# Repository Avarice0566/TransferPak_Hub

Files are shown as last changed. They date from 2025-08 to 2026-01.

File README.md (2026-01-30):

# TransferPakHub

This repository provides a standalone Transfer Pak hub PCB designed to fit inside an N64 DexDrive case.  

## Requirements
- Transplant all surface-mount and DIP components from an **N64 controller PCB** (model: `CFS8120-200010-00`).  
- Optionally, add a **1.8mm LED** with the appropriate resistor to utilize the DexDrive case’s LED diffuser.
- Digikey Part No. SW1139-ND can be used to plug the DC jack hole in the dexdrive case

## Notes
- All DIP components are mounted on the opposite side of the board for clearance.  
- **Use at your own risk.** I am not responsible for any damage to your N64, its accessories, or your Game Boy cartridges.  

N64TP_HUB

- Bottom label. Replaces Interact DEXDRIVE label with something that looks more akin to a real Nintendo product. (The label needs to be 26mm in height and 35mm in width)

TPpak hub label

Special thanks to Modman(RWeick), Bigbass, and everyone on the N64BREW Discord.

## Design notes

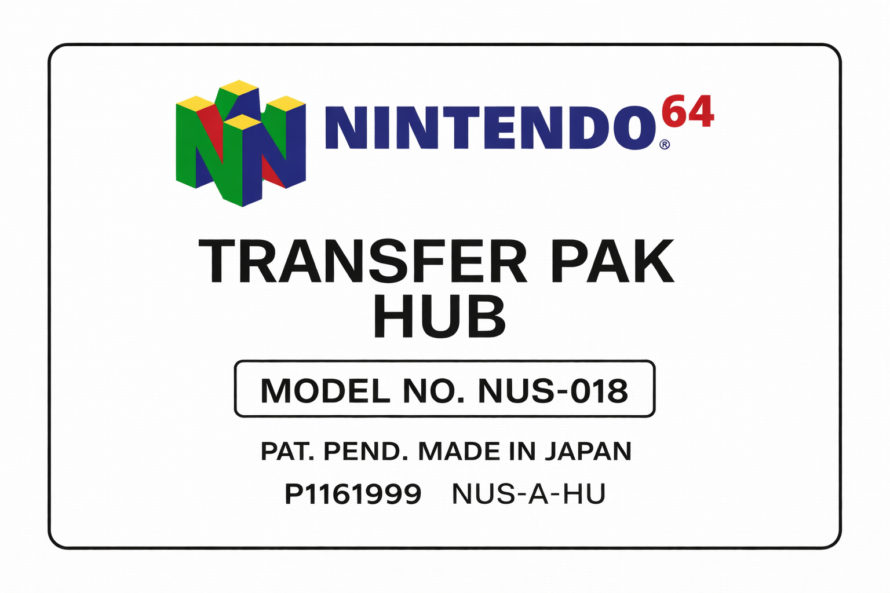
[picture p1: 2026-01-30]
TPpak hub label.png

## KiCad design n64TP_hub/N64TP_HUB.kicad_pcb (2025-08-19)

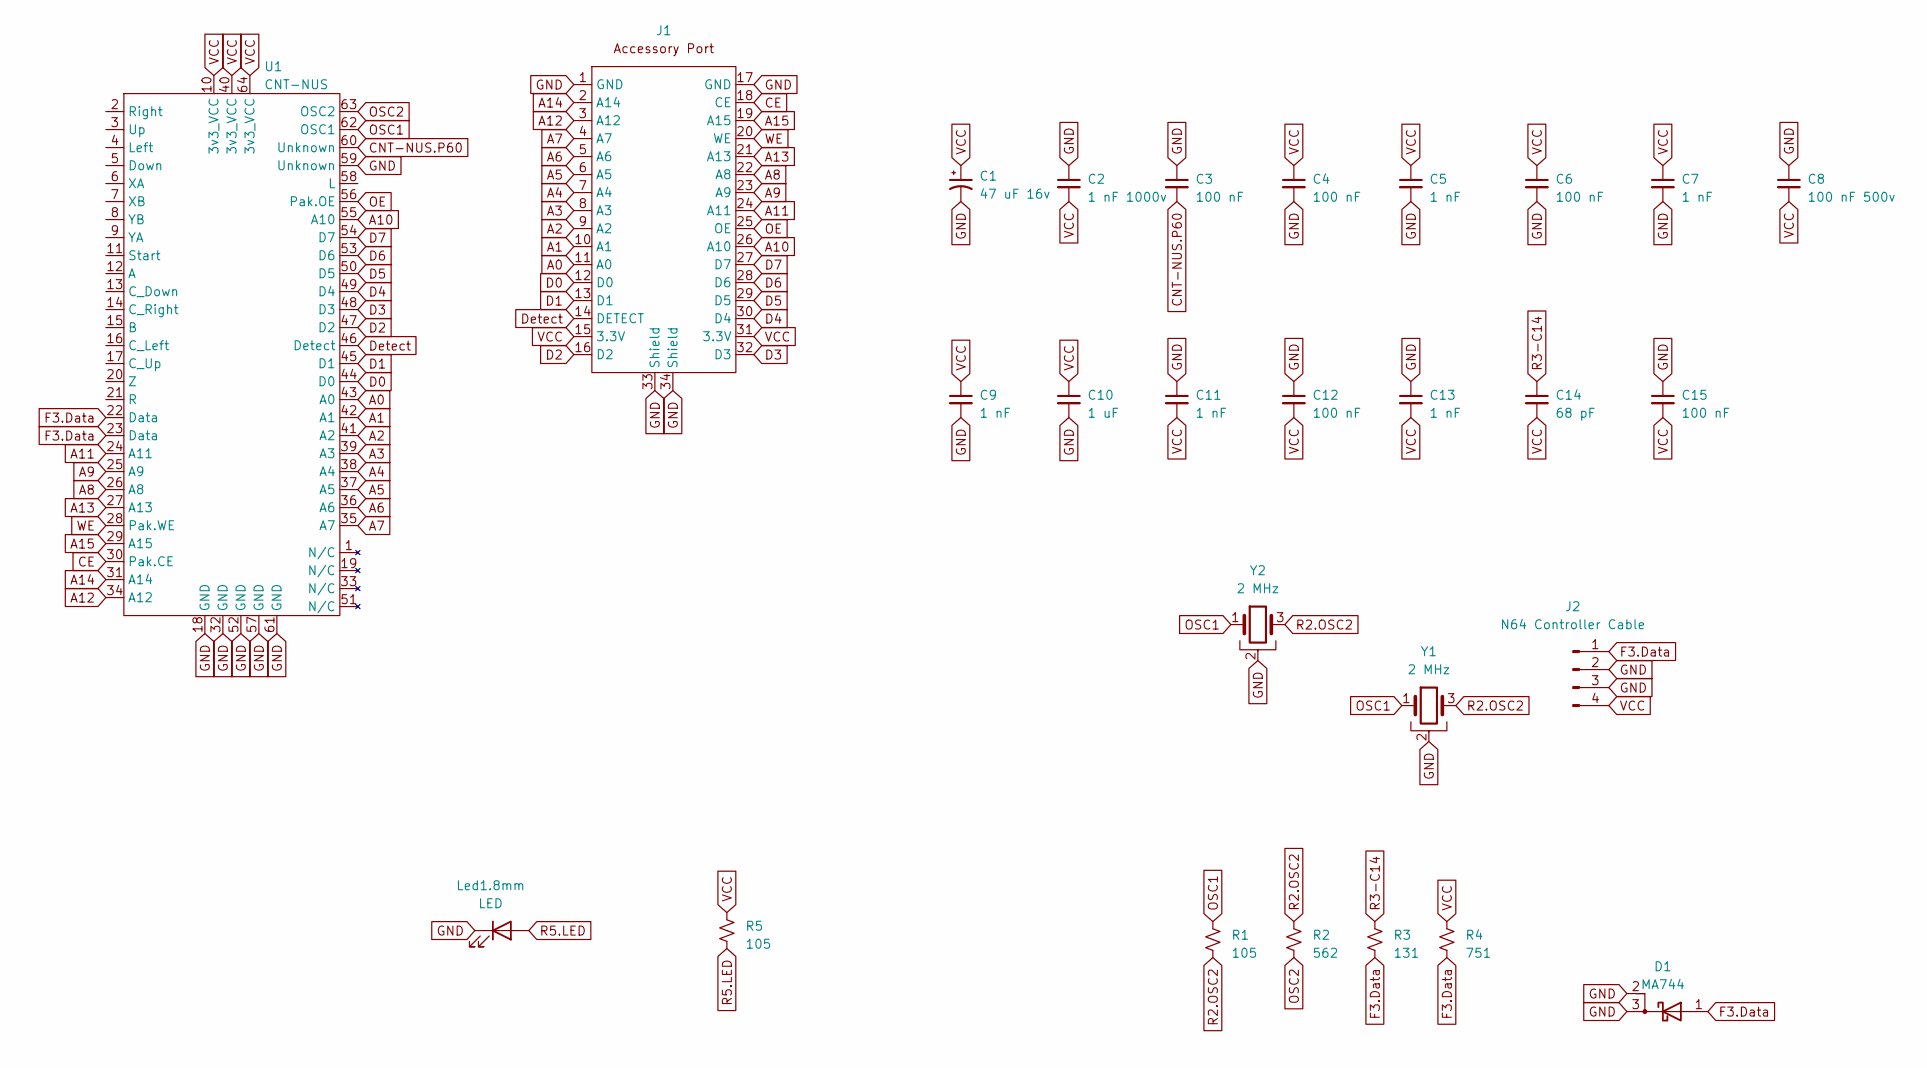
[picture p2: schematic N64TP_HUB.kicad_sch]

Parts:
C1: 47 uF 16v; CP_Radial_D5.0mm_P2.50mm
C2: 1 nF 1000v; TH Capacitor
C3, C4, C6, C12, C15: 100 nF; Small SMD
C5, C7, C9, C11, C13: 1 nF; Small SMD
C8: 100 nF 500v; TH Capacitor
C10: 1 uF; Small SMD
C14: 68 pF; Small SMD
D1: MA744; SOT-23 Diode
J1: Accessory Port
J2: N64 Controller Cable; N64 Plug Cable Connector
Led1.8mm: LED
R1, R5: 105; Large SMD
R2: 562; Large SMD
R3: 131; Small SMD
R4: 751; Small SMD
U1: CNT-NUS
Y1: 2 MHz; 2 MHz Oscillator
Y2: 2 MHz; 2 Mhz Oscillator SMD

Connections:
A: U1.12 (A)
A0: J1.11 (A0), U1.43 (A0)
A1: J1.10 (A1), U1.42 (A1)
A2: J1.9 (A2), U1.41 (A2)
A3: J1.8 (A3), U1.39 (A3)
A4: J1.7 (A4), U1.38 (A4)
A5: J1.6 (A5), U1.37 (A5)
A6: J1.5 (A6), U1.36 (A6)
A7: J1.4 (A7), U1.35 (A7)
A8: J1.22 (A8), U1.26 (A8)
A9: J1.23 (A9), U1.25 (A9)
A10: J1.26 (A10), U1.55 (A10)
A11: J1.24 (A11), U1.24 (A11)
A12: J1.3 (A12), U1.34 (A12)
A13: J1.21 (A13), U1.27 (A13)
A14: J1.2 (A14), U1.31 (A14)
A15: J1.19 (A15), U1.29 (A15)
B: U1.15 (B)
CD: U1.13 (C_Down)
CE: J1.18 (CE), U1.30 (Pak.CE)
CL: U1.16 (C_Left)
CNT-NUS.P60: C3.2, U1.60 (Unknown)
CR: U1.14 (C_Right)
CU: U1.17 (C_Up)
D0: J1.12 (D0), U1.44 (D0)
D1: J1.13 (D1), U1.45 (D1)
D2: J1.16 (D2), U1.47 (D2)
D3: J1.32 (D3), U1.48 (D3)
D4: J1.30 (D4), U1.49 (D4)
D5: J1.29 (D5), U1.50 (D5), U1.51 (D5)
D6: J1.28 (D6), U1.53 (D6)
D7: J1.27 (D7), U1.54 (D7)
Detect: J1.14 (DETECT), U1.46 (Detect)
Down: U1.5 (Down)
F3.Data: D1.1 (A), J2.1, R3.2, R4.2, U1.22 (Data), U1.23 (Data)
GND: C1.2, C2.1, C3.1, C4.2, C5.2, C6.2, C7.2, C8.1, C9.2, C10.2, C11.1, C12.1, C13.1, C15.1, D1.2 (K), D1.3 (K), J1.1 (GND), J1.17 (GND), J1.33 (Shield), J1.34 (Shield), J2.2, J2.3, Led1.8mm.1 (K), U1.18 (GND), U1.19 (Unknown), U1.32 (GND), U1.52 (GND), U1.57 (GND), U1.59 (Unknown), U1.61 (GND), Y1.2, Y2.2; also elsewhere on the board
L: U1.58 (L)
Left: U1.4 (Left)
OE: J1.25 (OE), U1.56 (Pak.OE)
OSC1: R1.1, U1.62 (OSC1), Y1.1, Y2.1
OSC2: R2.2, U1.63 (OSC2)
R: U1.21 (R)
R2.OSC2: R1.2, R2.1, Y1.3, Y2.3
R3-C14: C14.1, R3.1
Right: U1.2 (Right)
Start: U1.11 (Start)
Up: U1.3 (Up)
WE: J1.20 (WE), U1.28 (Pak.WE)
XA: U1.6 (XA)
XB: U1.7 (XB)
YA: U1.9 (YA)
YB: U1.8 (YB)
Z: U1.20 (Z)

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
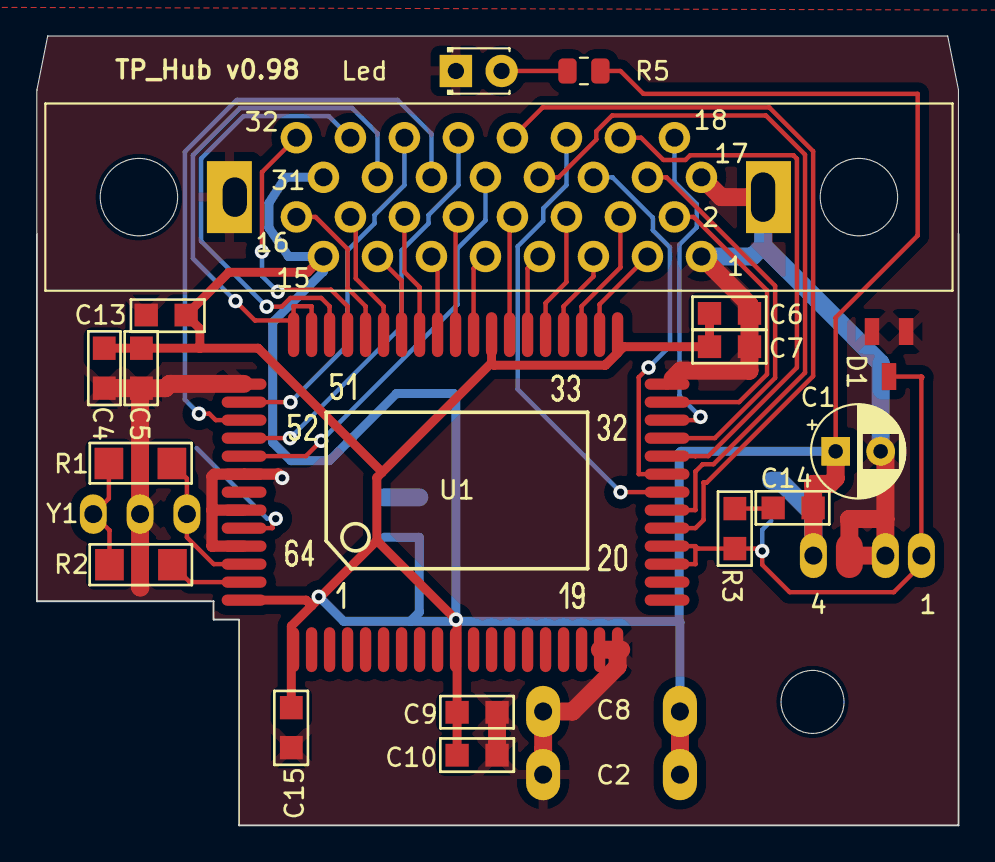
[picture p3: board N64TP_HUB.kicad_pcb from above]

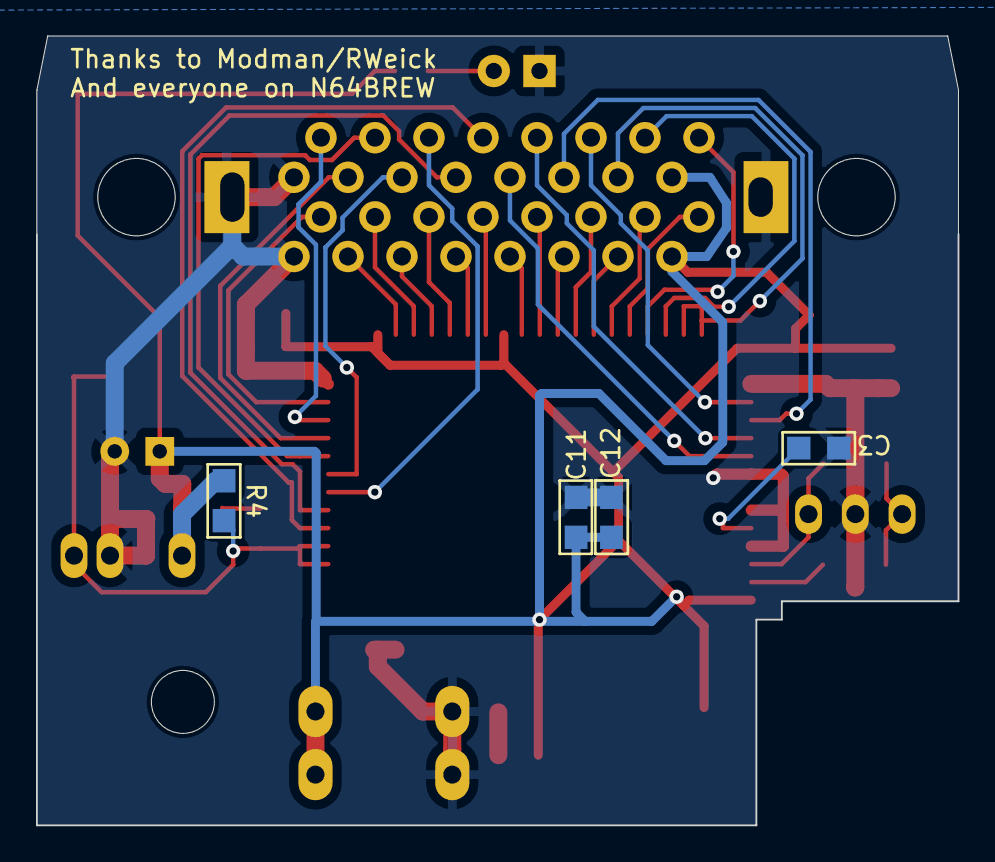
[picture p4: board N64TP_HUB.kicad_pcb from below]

Board: 2 copper layers, 51.2 x 43.9 mm, 26 parts (4 on the bottom side), 37 nets.

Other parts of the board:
Led: LED_D1.8mm_W3.3mm_H2.4mm

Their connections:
GND: Led.1; also elsewhere on the board
